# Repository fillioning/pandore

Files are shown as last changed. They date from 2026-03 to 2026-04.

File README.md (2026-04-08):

# Pandore

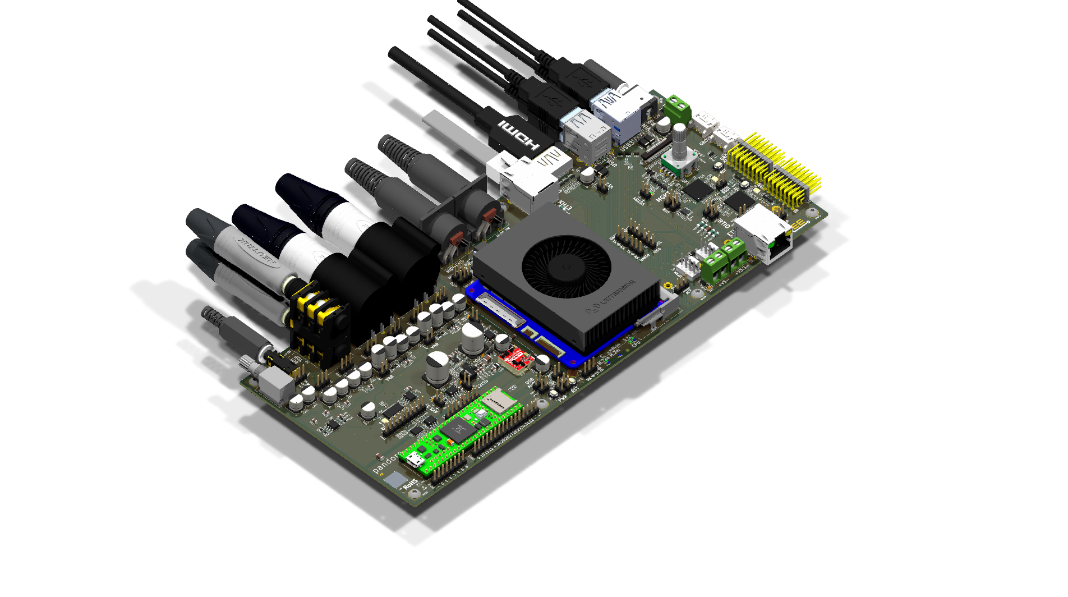
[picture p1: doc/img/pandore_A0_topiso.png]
Pandore A0


**Open-source digital audio instrument prototyping platform.**

Pandore is a custom-designed PCB built around the [LattePanda Mu](https://www.lattepanda.com/lattepanda-mu) compute module, a [Teensy 4.1](https://www.pjrc.com/store/teensy41.html) audio bridge, dual [RP2350](https://www.raspberrypi.com/products/rp2350/) microcontrollers, and a professional audio I/O chain. It provides a complete hardware foundation for building digital audio instruments, effects processors, and experimental sound tools.

## Status

**Revision A0** — PCBs fabricated (3 units). Manufacturing files released 2026-03-19. DRC passing, all components sourced.

> **PCBWay substitution:** RP2350A was unavailable at assembly time; PCBWay substituted **RP2350B (QFN-80)** for both MCU positions. RP2350A and RP2350B are binary-compatible — same cores, same peripherals, same memory map — they differ only in package size and number of exposed GPIO pins (30 vs 48). Firmware developed on RP2350A Pico boards transfers without modification.

## Board Specifications

| Parameter | Value |
|---|---|
| **Dimensions** | 260 mm x 110 mm |
| **Layers** | 4 (F.Cu / In1 / In2 / B.Cu) |
| **Components** | 804 (141 unique part numbers) |
| **Vias** | 2,217 |
| **Design tool** | KiCad 10 |

## Architecture

```
                         +-----------------+
                         |  LattePanda Mu  |
                         |  (x86-64 SBC)   |
                         +--------+--------+
                                  |
          +----------+-----------+-----------+----------+
          |          |                       |          |
 +--------+-------+  |             +---------+--------+ |
 |  RTIO MCU      |  |             |  Management MCU  | |
 |  (RP2350)      |  |             |  (RP2350)        | |
 +--------+-------+  |             +---------+--------+ |
          |          |                       |          |
 +--------+-------+  |             +---------+--------+ |
 | UART, SPI, I2C |  |             | GPIO, Power Seq, | |
 | ADC, 8x PWM    |  |             | Fan, Display     | |
 +----------------+  |             +------------------+ |
                     |                                  |
            +--------+--------+                         |
            |   Teensy 4.1    |                         |
            | (I2S-to-USB     |                         |
            |  Audio Bridge)  |                         |
            +--------+--------+                         |
                     |                                  |
            +--------+--------+               +---------+--------+
            |   CS4272 Codec  |               |   Boot, BIOS,    |
            |   (24-bit I2S)  |               |   Ethernet, M.2  |
            +-----------------+               +------------------+
```

### Compute

- **LattePanda Mu** — x86-64 SBC (Intel N100 or N305), main application processor. Recommended: DFR1147 (N100, 16 GB LPDDR5) — the N305 gives only ~13% single-core gain at ~2× cost, with no meaningful benefit for real-time audio workloads where single-thread performance dominates.
- **RTIO MCU (RP2350)** — Real-time I/O: UART, SPI, I2C, USB, ADC, 8x PWM channels
- **Management MCU (RP2350)** — System control: power sequencing, GPIO, fan, display, boot

### Audio

- **Audio/MIDI bridge:** [Teensy 4.1](https://www.pjrc.com/store/teensy41.html) — I2S-to-USB audio bridge between the CS4272 codec and the LattePanda Mu, also handles MIDI data transfer to the host computer
- **Codec:** Cirrus Logic CS4272 — stereo 24-bit ADC/DAC, I2S interface
- **Preamp:** THS4521 fully-differential amplifier + OPA1656 op-amp signal conditioning
- **Phantom power:** 48V supply via TI LM5158 flyback controller + TPS7A4001 ultra-low-noise 40V LDO post-regulation (~10 mA) for condenser microphones
- **I2S isolation:** TI ISO7762FDBQR — 6-channel digital isolator (4 forward / 2 reverse), 100 Mbps, 5000 VRMS galvanic isolation between digital and audio domains
- **I2C isolation:** TI ISO1640BDR — isolated I2C for codec control path, 2500 VRMS isolation
- **Isolated power:** Murata NXE2S1212MC — 1W isolated 12V→12V DC/DC converter for the isolated audio domain
- **MIDI isolation:** Isocom H11L1SMT optoisolator with Schmitt-trigger output on MIDI IN
- **Monitor output:** Dedicated headphone/speaker amplifier with hardware volume knob (Bourns PTR902-2020K-A103 — 10 kΩ audio taper, 20 mm shaft)
- **Input buffering:** Balanced input stage with line/mic switching
- **Output buffering:** Line-level outputs

### Power

| Rail | Voltage | Current | Purpose |
|---|---|---|---|
| 12V | Main input | LattePanda Mu, OLED drive |
| 5V | 2A (10W) | Digital logic, USB peripherals |
| 3.3V | 3A (10W) | MCUs, codec digital, I/O |
| 48V | 10 mA | Condenser microphone phantom power |
| AV5 / AV3P3 | — | Analog audio supply (isolated domain) |
| VSTBY | ~3.3V | Standby (CR2032 backup) |

**Power ICs:**

| Part | Role |
|---|---|
| Diodes AP63356Q (×2) | Synchronous buck converters (3.5A), main DC-DC regulation |
| STM LDL212DR (×3) | Ultra-low-dropout LDOs, local clean rails |
| ETEK ET20162 (×5) | Per-rail 5V load switching, 1A each |
| TI LM5158RTER | Flyback controller for 48V phantom supply |
| TI TPS7A4001DGNR | Ultra-low-noise 40V LDO, phantom post-regulation |
| Murata NXE2S1212MC | 1W isolated 12V DC/DC for audio analog domain |

- Reverse-polarity, overcurrent, and overvoltage protection
- PTC fuses (Bel Fuse) on USB VBUS
- Managed power-on sequencing via Management MCU

### Connectivity

- **Ethernet** — 2× Gigabit Ethernet via Realtek RTL8111H-CG PCIe controllers (U7, U8), 2× shielded RJ45 with isolation transformers (Würth 749020111A)
- **USB** — 8× USB from LattePanda Mu (3× USB 3.0 + 5× USB 2.0); 2× USB-C receptacles for Teensy 4.1 bridge
- **MIDI** — 5-pin DIN IN/OUT with H11L1 optoisolation
- **Display** — 24-pin 0.5mm FPC ZIF connector (GCT FFC2A32-24-T) for OLED status display (SSD1309, 128×64 px, 1.54") — see [Components Requiring Separate Assembly](#components-requiring-separate-assembly)
- **M.2 Key-M** — PCIe x4 (NVMe SSD)
- **M.2 Key-A+E** — WiFi/Bluetooth (tested: Intel AX210 — WiFi 6E tri-band + BT 5.3) or alternate storage
- **Expansion headers** — GPIO, analog, I/O breakouts; 2× Grove I2C connectors; I2S header; UART debug

### User Interface

- **Encoder:** Bourns PEL12T-4225T-S1024 — 24 PPR optical rotary encoder with momentary push switch and RGB LED illumination
- **Tactile switches:** 4× C&K PTS810 momentary switches (B1–B4)
- **Volume knob:** Bourns PTR902-2015K-B103 potentiometer (monitor output level)
- **RGBA LED:** AMS-OSRAM multi-colour LEDs — blue (×3), green (×4), orange (×7), red (×1) status/indicator outputs

### Sensors

- **BMI270** — 6-axis IMU (accelerometer + gyroscope) for motion-based control

### Flash Storage

3× Winbond W25Q128JVSIM (128 Mbit / 16 MB, QSPI):
- U2 — BIOS flash (LattePanda Mu)
- U5 — RTIO MCU flash (RP2350, U3)
- U6 — Management MCU flash (RP2350, U4)

### Thermal

- PWM-controlled fan driver circuit
- Three heatsink options: active cooler, thin passive, fanless

## Audio Performance

See **[Audio Performance](AUDIO_PERFORMANCE.md)** for the full signal chain, component specs, system-level estimates, physical I/O, and performance class.

**Highlights:** 24-bit / 192 kHz, 114 dB dynamic range, -100 dB THD+N, 5000 VRMS galvanic isolation, 2× Neutrik combo XLR+TRS inputs with 48V phantom power.

## Repository Structure

```
pandore/
  hw/               Schematics (.kicad_sch) and PCB layout (.kicad_pcb)
  doc/
    arch/           Architecture diagrams (draw.io)
    img/            Board renders
    reference/      Datasheets, app notes, design guides (PDF)
  lib/              3D models (.step), KiCad symbols and footprints
  release/          Manufacturing artifacts (Gerbers, BOM, placement, 3D)
```

### Schematic Hierarchy

The top-level schematic (`pandore.kicad_sch`) references 24 sub-sheets organized by subsystem:

**Audio** — `audio`, `audio-codec`, `audio-inputs`, `audio-inbuf`, `audio-outputs`, `audio-outbuf`, `audio-isolation`, `audio-monitor`, `audio-power`

**Compute** — `computer`, `cpumod`, `mcu`, `mgmtmcu`, `rtmcu`

**Power** — `power`, `audio-power`

**Interface** — `eth`, `usbport`, `midi`, `display`, `extraport`, `mdot2`

**System** — `bootctl`, `bios`, `fan`

## Components Requiring Separate Assembly

The PCBWay PCBA order covers all SMD components. The following through-hole and DNP parts must be sourced and hand-soldered separately. BOM part numbers are listed; substitutions are noted where a different part is recommended over the original BOM.

| BOM# | Per board | Ref | Description | Part (installed) | Notes |
|---|---|-----|---|---|---|
| 40 | 1 | E1 | Encoder + RGB LED + switch | Bourns **PEL12T-4225T-S1024** | 24 PPR, push switch, RGB illuminated |
| 47 | 2 | J4, J5 | Mic/Line input combo jack | Neutrik **NCJ9FI-H-0** | XLR + 6.35mm TRS + 3-way switch |
| 50 | 2 | J8, J9 | Ethernet RJ45 | Amphenol **RJE58-188-5411** | 8P8C shielded, dual LEDs, Cat5e |
| 51 | 2 | J10, J11 | MIDI DIN | Same Sky **SDS-50J** | 5-pin DIN 180° |
| 52 | 1 | J12 | Line output TRS | Neutrik **NSJ12HF-1** | 6.35mm stacking stereo |
| 55 | 2 | J15, J16 | GPIO expansion header | Samtec **MTSW-108-22-L-T-330-RA** | 3×8 right-angle, 2.54mm pitch |
| 56 | 2 | J17, J18 | Grove connectors | TE **440055-4** | HPI 2.0mm R/A THT (replaces BOM 2041145-4, same family) |
| 105 | 1 | R273 | Headphone volume pot | Bourns **PTR902-2020K-A103** | Audio taper, 20mm shaft (replaces BOM 2015K-B103, linear, 15mm) |
| — | 1 | J25 | OLED display panel | **Microtips REX012864AYAP3N00000** (primary) or Midas MCOT128064B1V-WM (alt) | SSD1309, 128×64, 24-pin 0.5mm FPC; J25 ZIF socket is PCBWay-assembled |
| — | 1 | J28/J29 | Audio/MIDI bridge module | **PJRC Teensy 4.1** | J28/J29 USB-C receptacles are PCBWay-assembled |
| — | 1 | J13 | NVMe SSD | User choice | M.2 2280 Key-M, PCIe x4 |
| — | 1 | J19 | WiFi/BT module | **Intel AX210** (WiFi 6E + BT 5.3) | M.2 2230 Key-E |

---

## Manufacturing

The `release/` directory contains two packages dated 2026-03-19 (revision A0):

- **`pandore_*_A0_pcba.zip`** — PCBA package: Gerbers, drill files, BOM (.csv), pick-and-place (.pos)
- **`pandore_*_A0_release.zip`** — Full release: PCBA files + 3D assembly model (.step), assembly drawings (PDF), rendered board images, ERC/DRC reports

4-layer stackup. 2,439 drill holes. All components have manufacturer part numbers assigned.

## Reference Documentation

The `doc/reference/` directory includes datasheets and design guides used during development:

- RP2350 datasheet and hardware design guide
- LattePanda Mu evaluation kit guide and carrier board reference
- CS4272 codec (via SuperAudioBoard design guide and schematic)
- THAT1512 microphone preamp gain configuration (reference design)
- 48V phantom power supply design (TI SBOA320A + ultra-low-noise RAQ approach)
- Analog circuit design references (Analog Secrets series, AES mic preamp paper)
- THAT Corporation mic preamp reference design (git submodule)

## Requirements

- [KiCad 10](https://www.kicad.org/) to open and edit schematics and PCB layout
- [draw.io](https://app.diagrams.net/) to view architecture diagrams

## Credits

Designed by **Vincent Fillion** at [Artificiel](https://artificiel.org), with the help of **Alexandre Burton**.

Hardware engineering and KiCad source files by **Laurence Deschênes Villeneuve** ([@laurencedv](https://github.com/laurencedv)).

## License

This project is licensed under the [CERN Open Hardware Licence Version 2 — Strongly Reciprocal (CERN-OHL-S-2.0)](https://ohwr.org/cern_ohl_s_v2.txt).

You are free to use, study, modify, and distribute this design, provided that:
- You credit the original authors
- You distribute any modified versions under the same licence
- You make the source files available

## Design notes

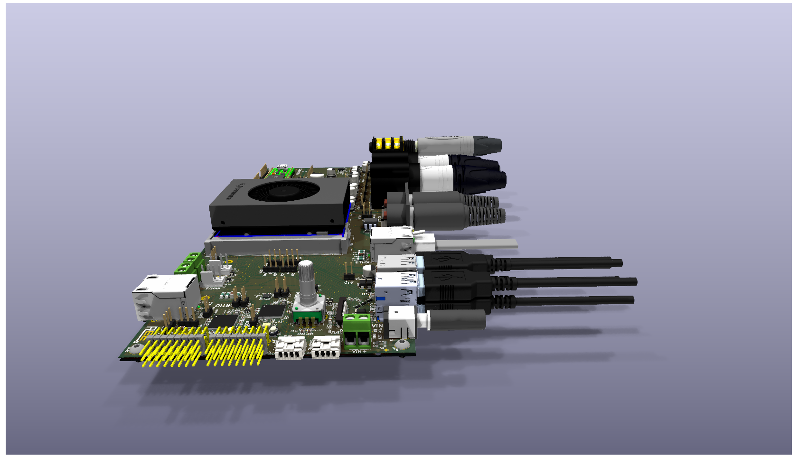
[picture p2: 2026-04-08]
doc/img/pandore-a0-connright.png

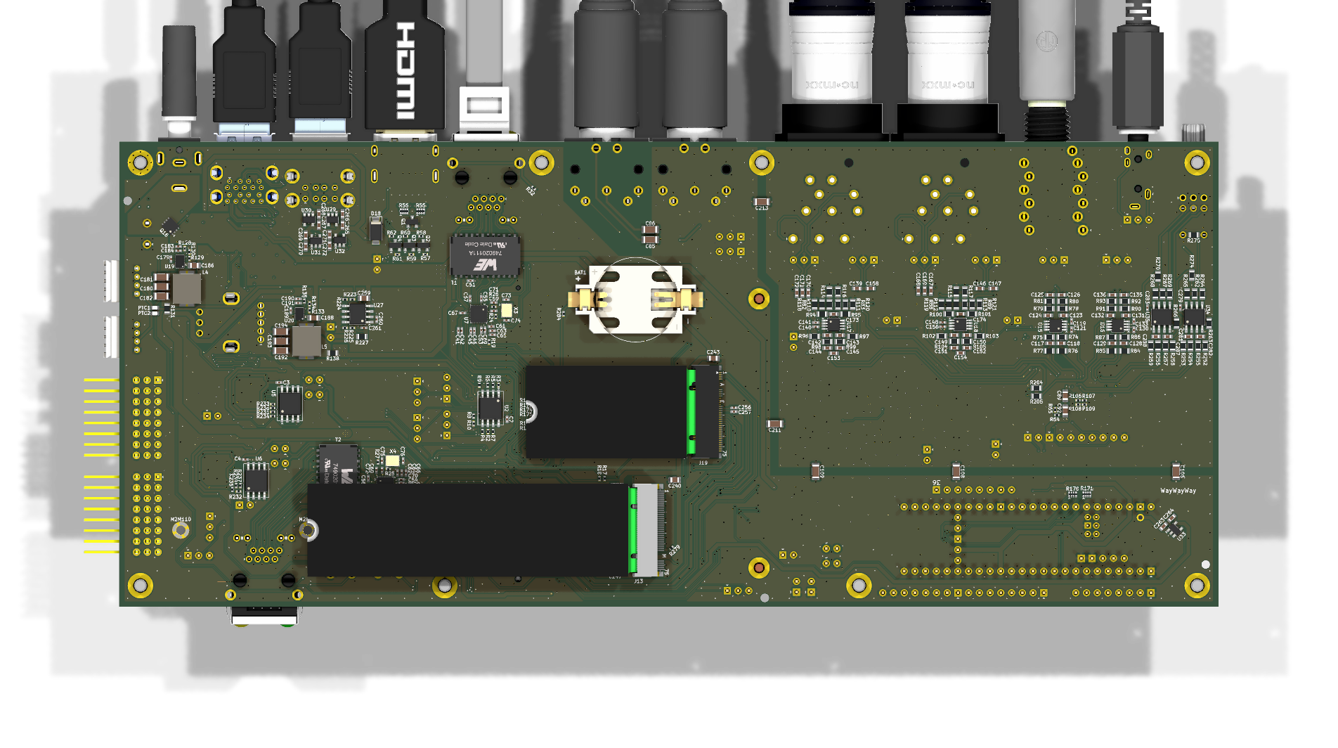
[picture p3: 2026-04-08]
doc/img/pandore_A0_bot.png

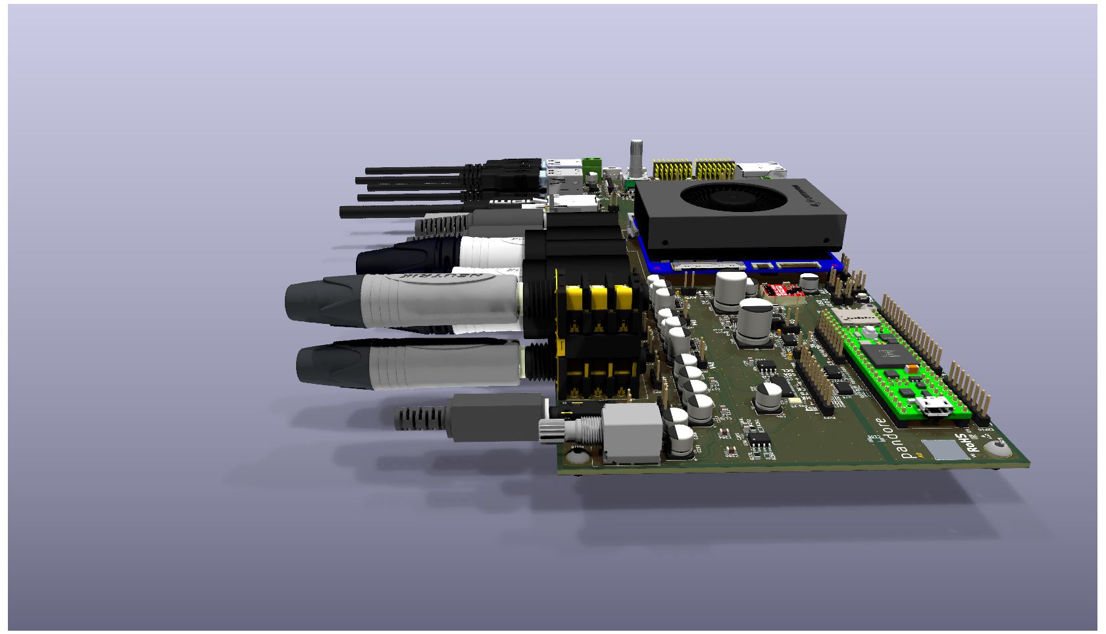
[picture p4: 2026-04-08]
doc/img/pandore-a0-connleft.png

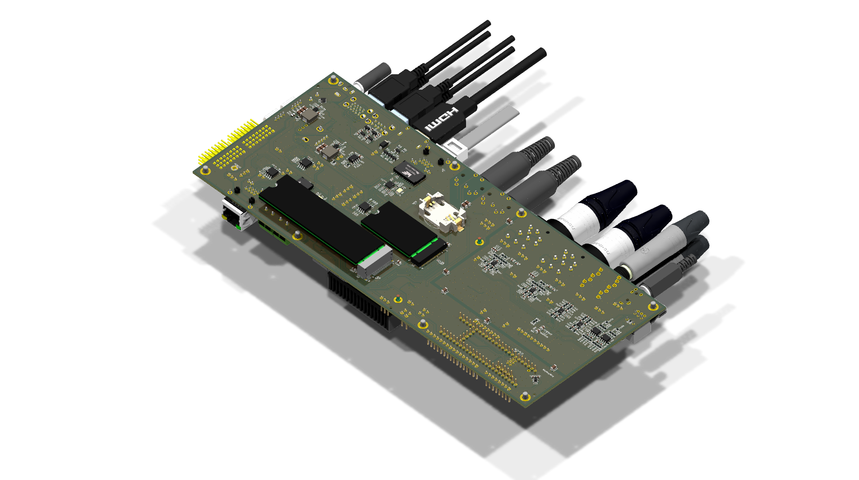
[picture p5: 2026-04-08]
doc/img/pandore_A0_botiso.png

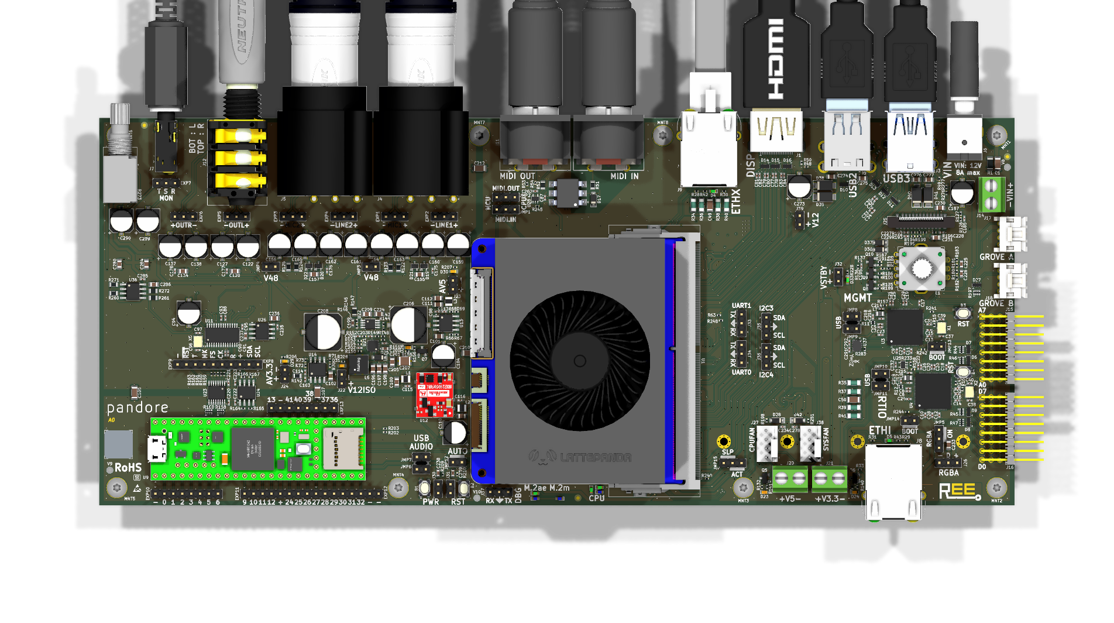
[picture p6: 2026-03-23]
doc/img/pandore_A0_top.png

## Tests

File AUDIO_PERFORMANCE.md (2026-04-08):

# Audio Performance

## Signal Chain

```
Mic/Line In (Neutrik XLR+TRS combo)
    → THS4521 Diff Amp → OPA1656 Conditioning → Input Buffer
        → CS4272 ADC (24-bit, up to 192 kHz)
            → I2S → ISO7762 Galvanic Isolation → I2S
                → Teensy 4.1 (I2S ↔ USB Audio Bridge)
                    → USB → LattePanda Mu
                        → USB → Teensy 4.1
                            → I2S → ISO7762 → I2S
                                → CS4272 DAC
                                    → Output Buffer → Line Out (Neutrik TRS)
                                    → Monitor Amp (volume knob) → Headphones (3.5mm TRS)
```

## Component Specs

| Component | Role | Key Specs |
|---|---|---|
| **CS4272** (Cirrus Logic) | Stereo codec | 24-bit, 4–192 kHz, 114 dB dynamic range (A-wtd), -100 dB THD+N |
| **THS4521** (TI, ×4) | Fully-differential amp | 4.6 nV/√Hz noise, -112 dB THD+N @ 1 kHz, 145 MHz BW, 490 V/µs, 102 dB CMRR |
| **OPA1656** (TI, ×4) | Dual op-amp | 2.9 nV/√Hz noise, -131 dB THD @ 1 kHz, 53 MHz GBW, 24 V/µs |
| **ISO7762** (TI) | I2S digital isolator | 6-ch (4F/2R), 100 Mbps, 11 ns delay, 5000 VRMS isolation |
| **ISO1640** (TI) | Isolated I2C (codec control) | 1 Mbps, 2500 VRMS isolation |
| **NXE2S1212MC** (Murata) | Isolated 12V DC/DC | 1W, 12V→12V, powers isolated audio domain |
| **H11L1** (Isocom) | MIDI IN optoisolator | Schmitt-trigger output |
| **Teensy 4.1** (PJRC) | Audio/MIDI bridge | Cortex-M7 @ 600 MHz, 2× I2S, USB Audio class-compliant |

## System-Level Estimates

The analog front-end (OPA1656 at -131 dB THD, THS4521 at -112 dB) significantly exceeds the codec's performance floor — the **CS4272 is the limiting factor**, not the preamp stage.

| Parameter | Expected Value |
|---|---|
| **Dynamic range** | 112–114 dB (A-weighted) |
| **THD+N (system)** | -98 to -100 dB (codec-limited) |
| **Noise floor** | ~-114 dBFS (A-weighted) |
| **Max sample rate** | 192 kHz / 24-bit |
| **USB audio latency** | ~5–10 ms round-trip (buffer-dependent) |
| **Frequency response** | 20 Hz – 90 kHz (at 192 kHz) |
| **Phantom power** | 48V / 10 mA |
| **Channel separation** | >100 dB |
| **Galvanic isolation** | 5000 VRMS (digital ↔ audio domain) |

## Physical I/O

| Connector | Part | Type |
|---|---|---|
| Mic/Line In (×2) | Neutrik NCJ9FI-H-0 | Combo XLR + 6.35mm TRS + 3-way switch |
| Line Out (×1) | Neutrik NSJ12HF-1 | 6.35mm TRS |
| Monitor | Same Sky SJ3-35083B-TR | 3.5mm TRS |
| MIDI In/Out | Same Sky SDS-50J (×2) | 5-pin DIN |
| Teensy USB | Same Sky CPG-23-SMT-TR (×2) | USB-C |

## Performance Class

Comparable to prosumer interfaces (Focusrite Scarlett, MOTU M4). The 114 dB dynamic range is well above the noise floor of any live performance or instrument prototyping scenario. The analog front-end is essentially transparent — the OPA1656's -131 dB THD provides substantial headroom over the codec.

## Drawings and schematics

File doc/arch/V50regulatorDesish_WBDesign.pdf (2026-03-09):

## WEBENCH ® Design Report

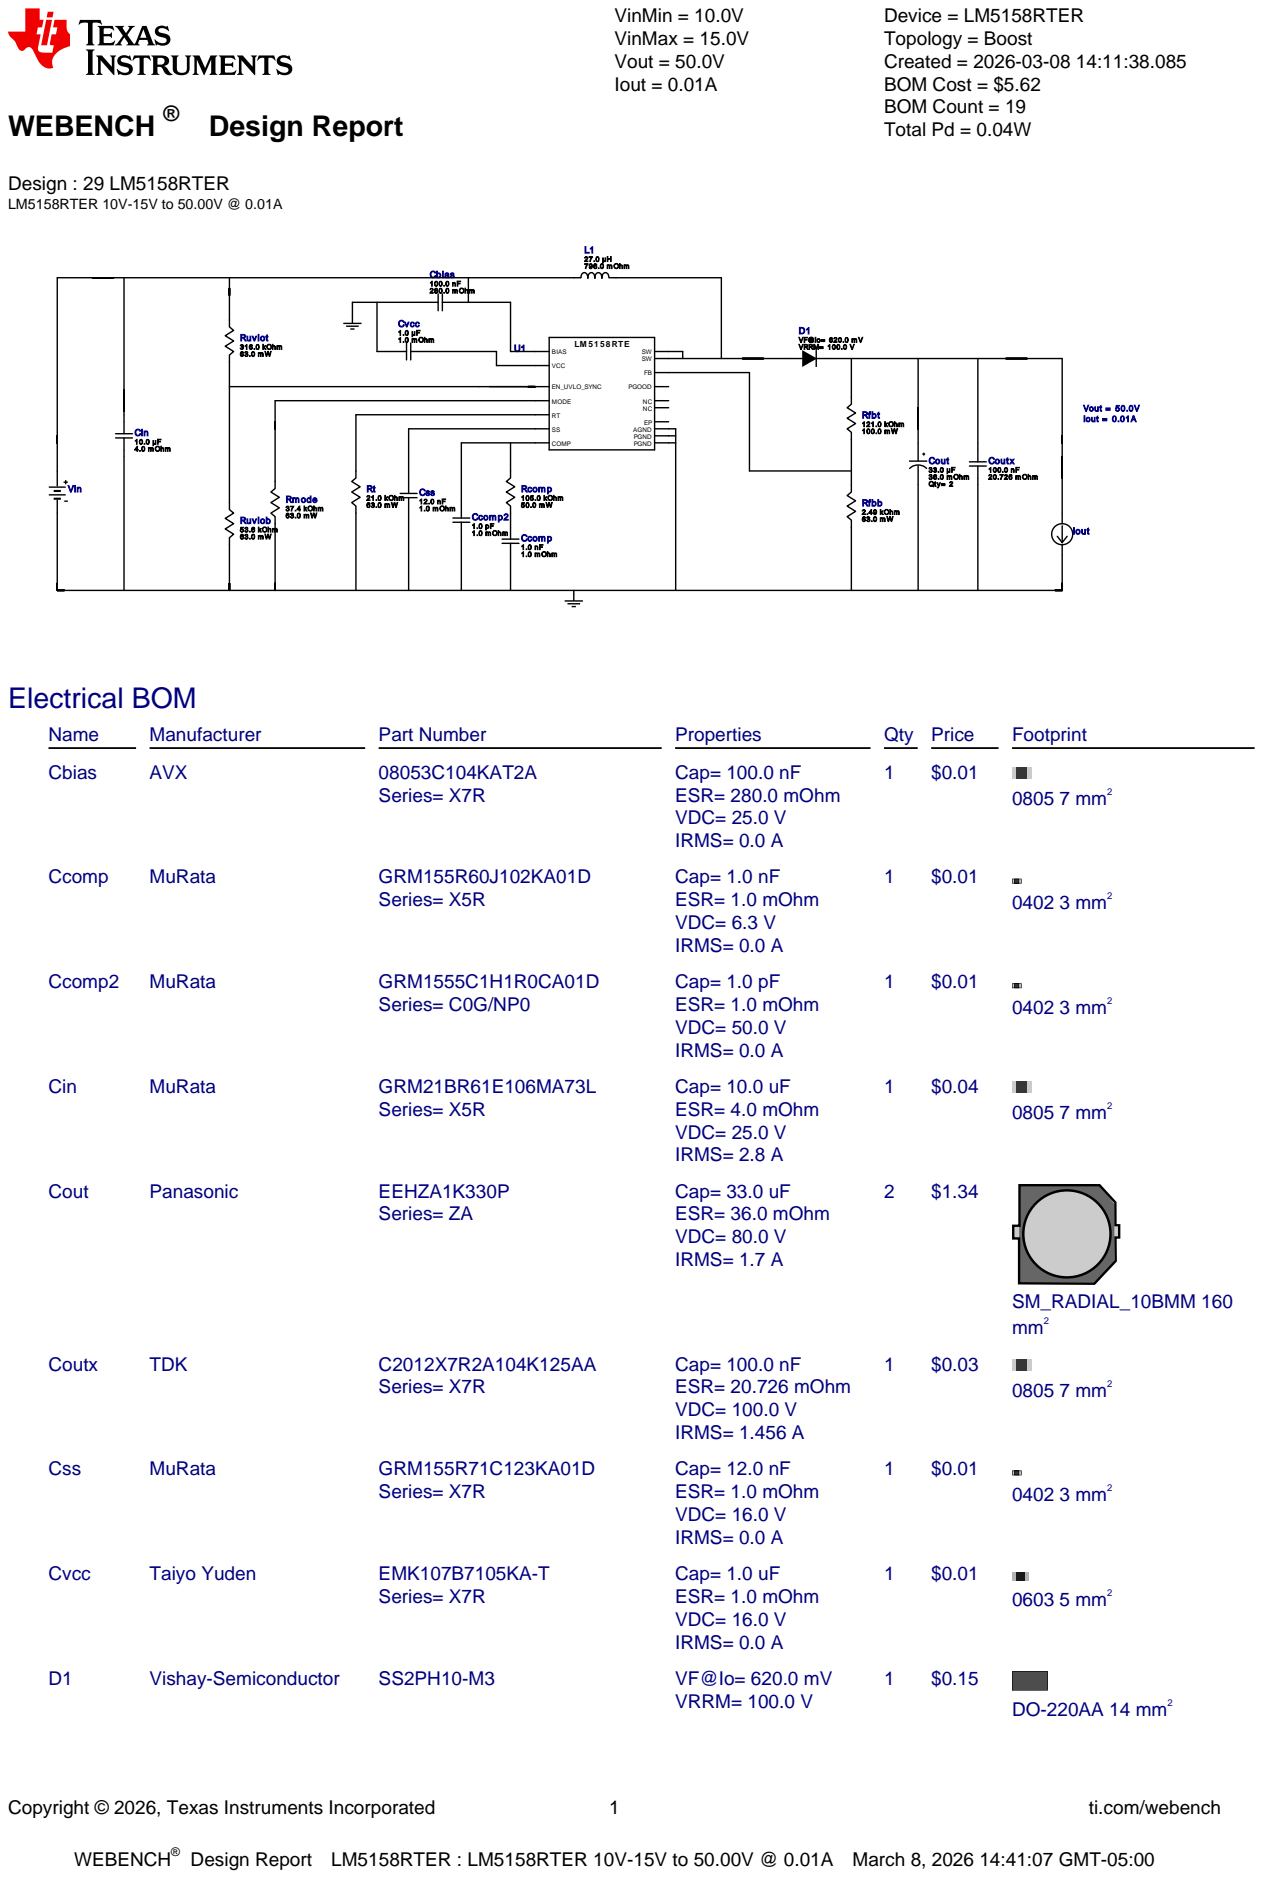
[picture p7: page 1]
Copyright © 2026, Texas Instruments Incorporated; ti.com/webench; WEBENCH®; Design : 29 LM5158RTER LM5158RTER 10V-15V to 50.00V @ 0.01A; VinMin = 10.0V VinMax = 15.0V Vout = 50.0V Iout = 0.01A; Device = LM5158RTER Topology = Boost Created = 2026-03-08 14:11:38.085 BOM Cost = $5.62 BOM Count = 19 Total Pd = 0.04W; Rt 21.0 kOhm; Ccom p 1.0 nF 1.0 m Ohm; Cin 10.0 µF 4.0 m Ohm; Rfbb 2.49 kOhm 63.0 m W; Rfbt 121.0 kOhm; L1 27.0 µH 796.0 m Ohm; Ruvlob 53.6 kOhm 63.0 m W; Ruvlot 316.0 kOhm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

VRRM= 100.0 V LM 5 1 5 8 RTE

Design Report LM5158RTER : LM5158RTER 10V-15V to 50.00V @ 0.01A March 8, 2026 14:41:07 GMT-05:00

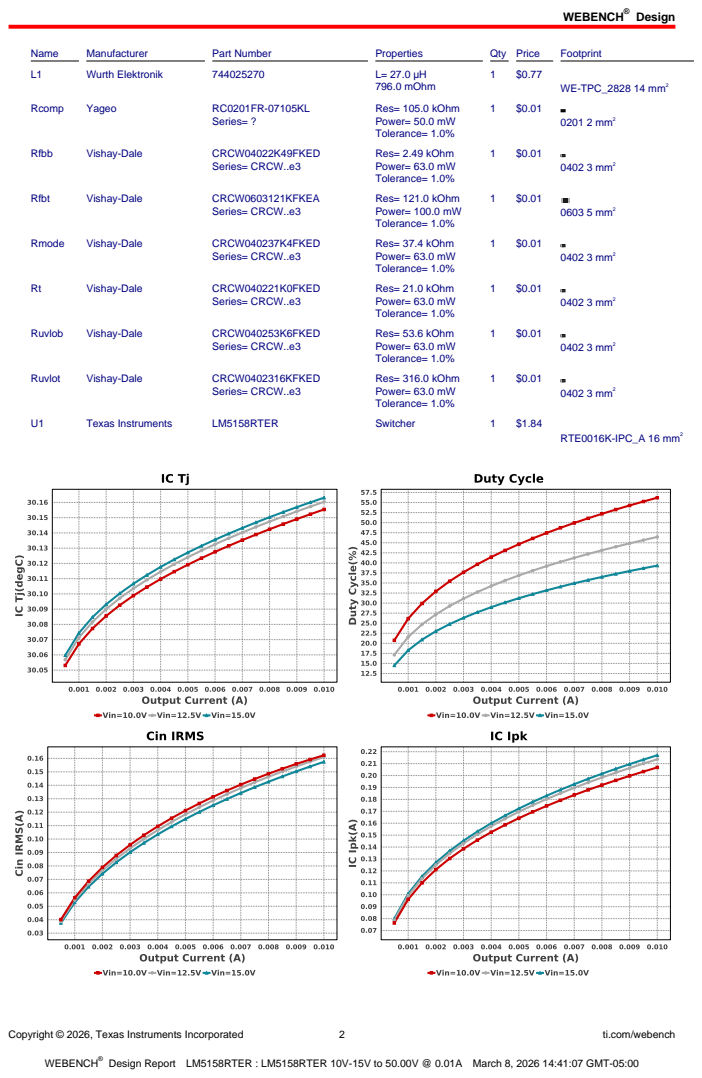
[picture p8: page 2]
Design; Copyright © 2026, Texas Instruments Incorporated; ti.com/webench; Name; Manufacturer; Part Number; Properties; Qty Price; Footprint; Wurth Elektronik; 796.0 mOhm; WE-TPC_2828 14 mm²; Rcomp; Yageo; Series= ?; Res= 105.0 kOhm Power= 50.0 mW Tolerance= 1.0%; 0201 2 mm²; Rfbb; Vishay-Dale; CRCW04022K49FKED; Series= CRCW..e3; Res= 2.49 kOhm Power= 63.0 mW Tolerance= 1.0%; 0402 3 mm²; Rfbt; CRCW0603121KFKEA; Res= 121.0 kOhm Power= 100.0 mW Tolerance= 1.0%; 0603 5 mm²; Rmode; CRCW040237K4FKED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

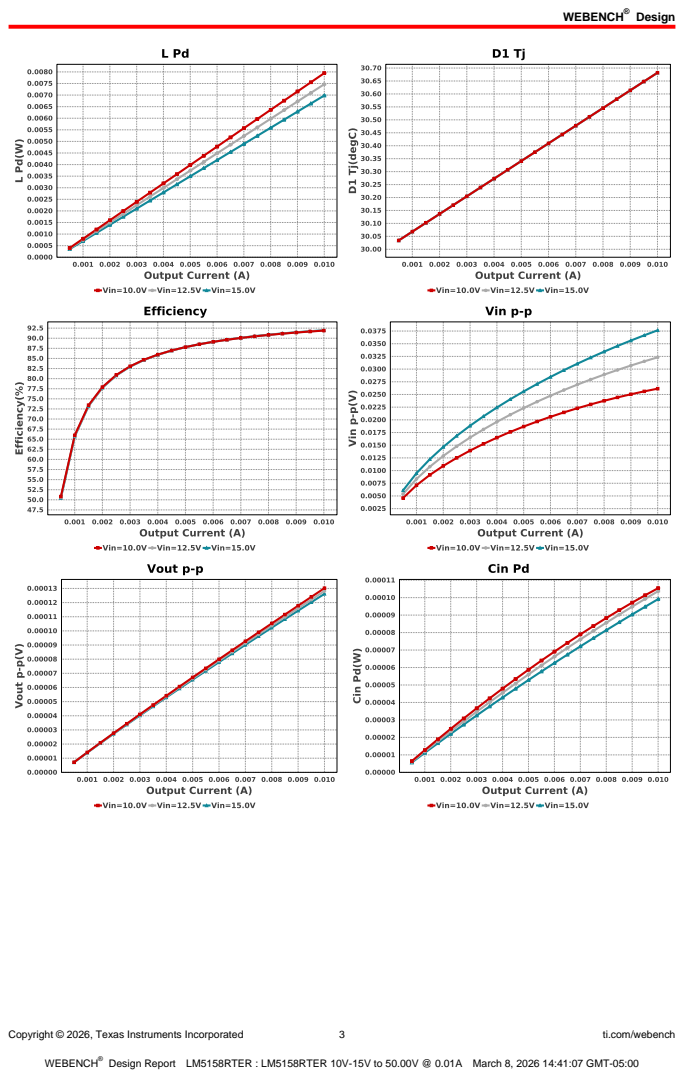
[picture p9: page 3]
Copyright © 2026, Texas Instruments Incorporated; ti.com/webench

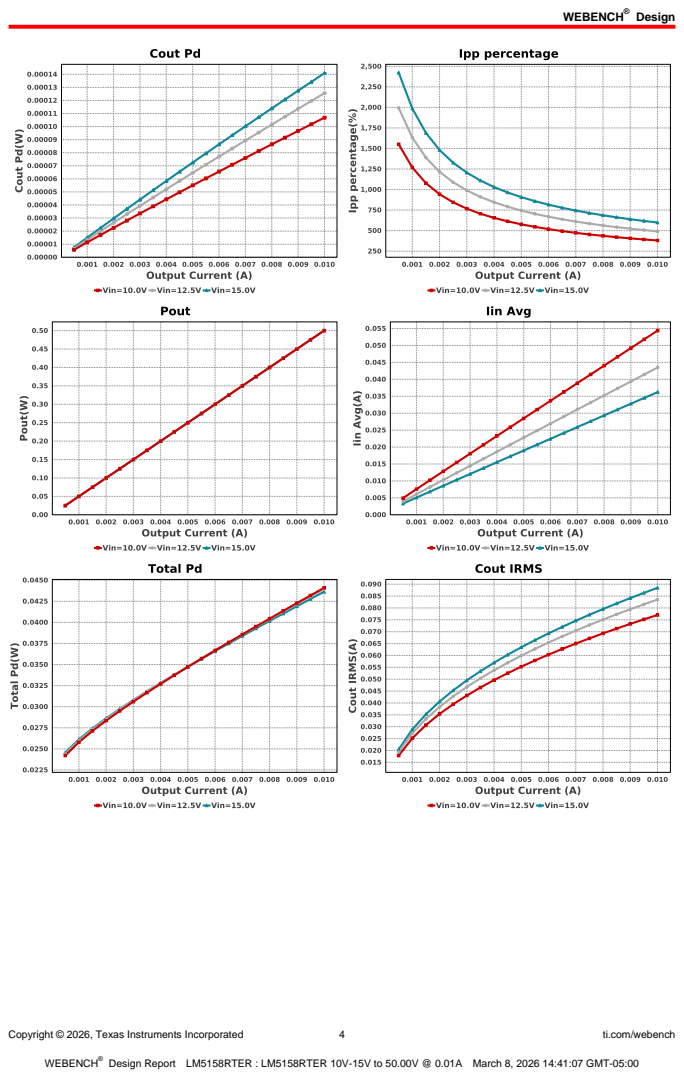
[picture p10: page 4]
Copyright © 2026, Texas Instruments Incorporated; ti.com/webench

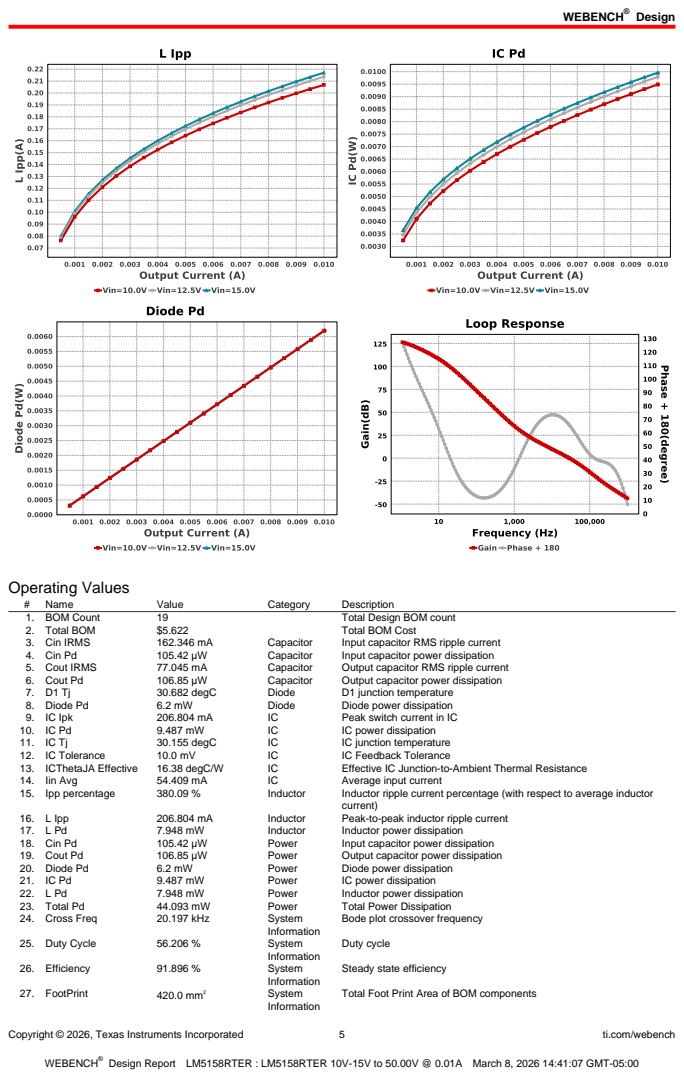
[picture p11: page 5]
Copyright © 2026, Texas Instruments Incorporated; ti.com/webench; Operating Values; Name; Value; Category; Description; 1. BOM Count; Total Design BOM count; 2. Total BOM; Total BOM Cost; 3. Cin IRMS; Capacitor; Input capacitor RMS ripple current; 4. Cin Pd; Input capacitor power dissipation; 5. Cout IRMS; Output capacitor RMS ripple current; 6. Cout Pd; Output capacitor power dissipation; 30.682 degC; Diode; D1 junction temperature; 8. Diode Pd; Diode power dissipation; 9. IC Ipk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

Bode plot crossover frequency

Steady state efficiency

Total Foot Print Area of BOM components

Copyright © 2026, Texas Instruments Incorporated | 6 | ti.com/webench
# | Name | Value | Category | Description

28. Frequency | 1.007 MHz | System
| | | Information | Switching frequency
29. Gain Marg | -42.993 dB | System
| | | Information | Bode Plot Gain Margin
30. Iout | 10.0 mA | System
| | | Information | Iout operating point
31. Low Freq Gain | 122.835 dB | System
| | | Information | Gain at 1Hz
32. Mode | DCM | System
| | | Information | Conduction Mode
33. Phase Marg | 70.569 deg | System
| | | Information | Bode Plot Phase Margin
34. Pout | 500.0 mW | System
| | | Information | Total output power
35. Vin | 10.0 V | System
| | | Information | Vin operating point
36. Vin p-p | 26.145 mV | System
| | | Information | Input Source ripple voltage
37. Vout | 50.0 V | System
| | | Information | Operational Output Voltage
38. Vout Actual | 49.594 V | System
| | | Information | Vout Actual calculated based on selected voltage divider resistors
39. Vout Tolerance | 2.999 % | System
| | | Information | Vout Tolerance based on IC Tolerance (no load) and voltage divider resistors if applicable
40. Vout p-p | 130.206 µV | System
| | | Information | Peak-to-peak output ripple voltage

## Design Inputs

Name | Value | Description
Iout | 10.0 m | Maximum Output Current
SoftStart | 1.0 ms | Soft Start Time (ms)
VinMax | 15.0 | Maximum input voltage
VinMin | 10.0 | Minimum input voltage
Vout | 50.0 | Output Voltage
| base_pn | | LM5158 | Base Product Number
source | DC | Input Source Type
Ta | 30.0 | Ambient temperature
| UserFsw | | 1000.0 k | Customer Selected Frequency


Copyright © 2026, Texas Instruments Incorporated | 7 | ti.com/webench

## Assembly

## Component Testing

Some published data on components in datasheets such as Capacitor ESR and Inductor DC resistance is based on conservative values that will guarantee that the components always exceed the specification. For design purposes it is usually better to work with typical values. Since this data is not always available it is a good practice to measure the Capacitance and ESR values of Cin and Cout, and the inductance and DC resistance of L1 before assembly of the board. Any large discrepancies in values should be electrically simulated in WEBENCH to check for instabilities and thermally simulated in WebTHERM to make sure critical temperatures are not exceeded.
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

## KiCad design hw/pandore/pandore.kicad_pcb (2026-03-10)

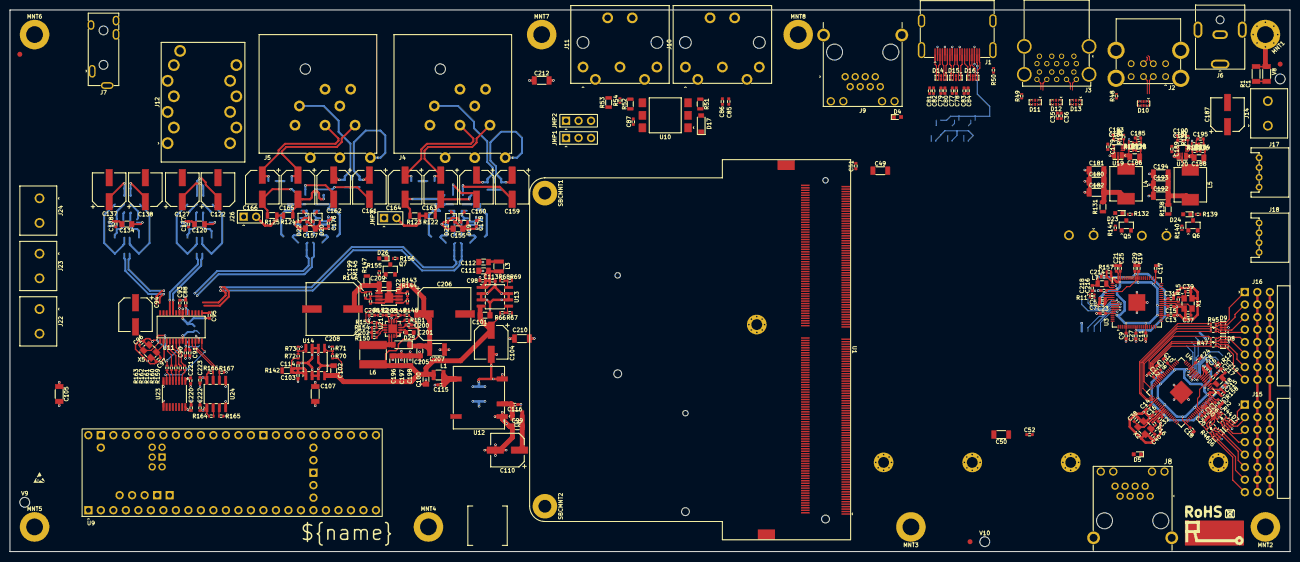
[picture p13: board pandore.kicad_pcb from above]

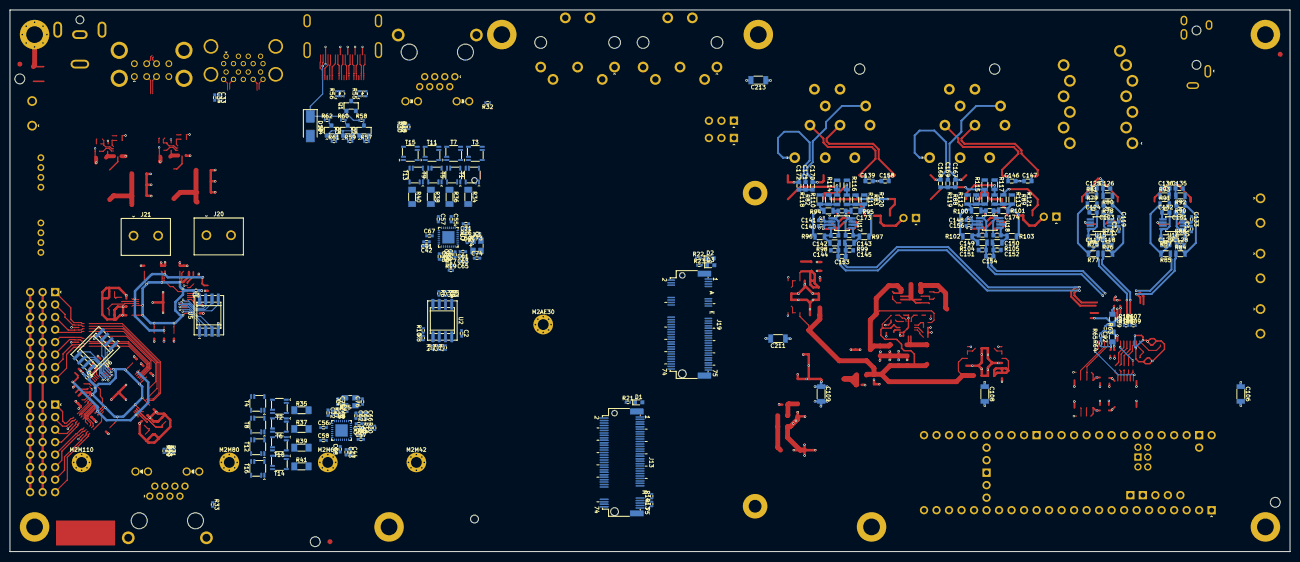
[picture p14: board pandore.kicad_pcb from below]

Board: 4 copper layers, 260.0 x 110.0 mm, 530 parts (227 on the bottom side), 432 nets.

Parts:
C1: 10nF, 630V, X7R; CAPC3216
C2, C3, C4, C5, C6, C7, C8, C9, C10, C11, C12, C13, C14, C15, C16, C17, C18, C19, C20, C21, C22, C23, C24, C25, C26, C27, C28, C29, C30, C33, C34, C35, C36, C41, C42, C43, C44, C45, C46, C47, C48, C51, C52, C53, C54, C55, C56, C57, C58, C59, C60, C61, C62, C67, C68, C69, C70, C71, C72, C77, C78, C79, C80, C81, C82, C83, C84, C85, C86, C87, C88, C90, C91, C93, C95, C113, C114, C119, C133, C140, C156, C175, C176, C177, C178, C179, C189, C220, C221, C222, C223: 100nF, 16V, X7R; CAPC1005
C31, C32, C63, C64, C65, C66, C98, C103, C214, C215, C216, C217, C218, C219: 4.7µF, 6.3V, X5R; CAPC1005
C37, C38, C39, C40: 15pF, 6.3V, X7R; CAPC1005
C49, C50: 1nF, 1000V, X7R; CAPC3216
C73, C74, C75, C76, C96, C97: 12pF, 6.3V, X7R; CAPC1005
C89, C92: 10µF, 16V, X5R; CAPC2012
C94, C104, C110: 47µF, 25V, 20%; CAPAE630Xxxx
C99, C100, C101, C102, C111, C112, C120, C134, C155, C157, C186, C188, C196, C197, C198: 10µF, 25V, X5R; CAPC2012
C105, C106, C107, C108, C109, C210, C211, C212, C213: 100pF, 1kV, X5R; CAPC3216
C115, C116, C200: 100nF, 25V, X7R; CAPC1005
C117, C118, C128, C129: 1.3nF, 16V, C0G; CAPC1608
C121, C130, C141, C148: 220nF, 16V, X7R; CAPC1005
C122, C127, C137, C138, C159, C160, C161, C162, C187: 100µF, 25V, 20%; CAPAE630Xxxx
C123, C124, C131, C132: 300pF, 16V, C0G; CAPC1608
C125, C126, C135, C136: 33nF, 16V, C0G; CAPC1608
C139, C144, C145, C146, C147, C151, C152, C158, C167, C168, C169, C170, C171, C172, C173, C174: 100pF, 50V, C0G; CAPC1608
C142, C143, C149, C150: 1nF, 16V, C0G; CAPC1608
C153, C154: 2.7nF, 16V, C0G; CAPC1608
C163, C164, C165, C166: 47µF, 100V, 20%; CAPAE630Xxxx
C180, C181, C182, C192, C193, C194: 22µF, 25V, X5R; CAPC3216
C183, C190, C204: 1nF, 16V, X7R; CAPC1005
C184, C191: 68pF, 10V, X7R; CAPC1005
C185, C195: 47pF, 10V, X7R; CAPC1005
C199: 10nF, 100V, X7R; CAPC1005
C201: 1µF, 16V, X7R; CAPC1608
C202: 12nF, 16V, X7R; CAPC1005
C203: 1pF, 16V, X7R; CAPC1005
C205, C209: 100nF, 100V, X7R; CAPC2012
C206, C208: 56µF, 100V, 20%; CAPAE1000Xxxx
C207: 10µF, 100V, X5R; CAPC3225
D1, D2, D3, D4, D5, D23, D24, D26: green; LEDM1608X80
D6, D7, D8, D9, D10, D11, D12, D13, D14, D15, D16: 5V; DFN50P100X250X55-10_ESD204
D17: 75V, 150mA, 1V@100mA; sod-123
D18: 40V, 3A, 500mV@3A; dio_sma
D19, D20, D21, D22: 75V, 140mA, 1.25V@150mA; SOT65P210X90-3
D25: 100V, 150mA, 450mV@10mA; sod-123
J1: HDMI; te_1747981-1
J2: USB2-A_2stacked; USB2_A_RCPT_HORZ_2STACKED
J3: USB3-A_2stacked; USB3_A_RCPT_HORZ_2STACKED
J4, J5: XLR+TRS6.35+3SW; neutrik_ncj9fi-h-0
J6: VIN; samesky_PJ-063BH
J7: TRS; samesky_SJ3-3508x
J8, J9: 8p8c_2led_shield; amphenol_RJE58-188-54x1-0x
J10: MIDI_in; samesky_SDS-50J
J11: MIDI_out; samesky_SDS-50J
J12: TRS; neutrik_nsj12hf-1
J13: NGFF_M.2_M; NGFF_M.2_CONN
J14: VIN; Wurth_691137710002
J15: AIO; HDR254P3X8-THRA
J16: DIO; HDR254P3X8-THRA
J17, J18: GROVE; te_2041145-4
J19: NGFF_M.2_AE; NGFF_M.2_CONN
J20: V5; Wurth_691137710002
J21: V3.3; Wurth_691137710002
J22: V12ISO; Wurth_691137710002
J23: AV5; Wurth_691137710002
J24: AV3P3; Wurth_691137710002
J26: PPWR; HDR254P1X02-TH
JMP1: MIDIRX; HDR254P1X03-TH
JMP2: MIDITX; HDR254P1X03-TH
JMP3: PPWR; HDR254P1X02-TH
L1, L2, L3: 10µH; INDC2520
L4, L5: 8.2µH, 5A; Eaton_HPAL1V0630
L6: Ind; WE_IND5030
L7, L8: 3.3µH, 1.8A; INDC2012
M2AE30, M2M42, M2M60, M2M80, M2M110: M2; mnt_M2_ele
MNT1: MNT-CHASSIS; mnt_M3_ele
MNT2, MNT3, MNT4, MNT5, MNT6, MNT7, MNT8: Mounting; mnt_M3
Q1, Q2, Q3, Q4, Q5, Q6, Q7: MOSFET_EN-N; SOT95P280X100-3
R1: 1MΩ, 5%, 250mW; RESC3216
R2, R3, R4, R5, R6, R7: 0, 5%, 63mW; RESC1005
R8, R9, R10, R13, R17, R18, R19, R20, R64, R66, R67, R68, R69, R70, R71, R72, R73, R106, R107, R108, R109, R129, R130, R133, R134, R140, R141, R143, R144, R145, R146, R155: 10kΩ, 1%, 63mW; RESC1005
R11, R12: 27Ω, 5%, 63mW; RESCAXSR65P100X100X35-4
R14, R15, R16, R21, R22, R23, R42, R43, R65, R132, R139, R156: 1kΩ, 1%, 63mW; RESC1005
R24, R25: 1MΩ, 1%, 63mW; RESC1005
R26, R27: 2.49kΩ, 1%, 63mW; RESC1005
R28, R29, R30, R31: 470Ω, 1%, 63mW; RESC1005
R32, R33, R48, R49, R50, R54, R63: 0Ω, 5%, 63mW; RESC1005
R34, R35, R36, R37, R38, R39, R40, R41: 75Ω, 1%, 250mW; RESMELF0204
R44, R45, R46, R47, R55, R56: 560Ω, 5%, 63mW; RESCAXSR50P200X100X35-8
R51: 220Ω, 1%, 250mW; RESC2012
R52: 10Ω, 1%, 250mW; RESC2012
R53: 33Ω, 1%, 250mW; RESC2012
R57, R58, R59, R60, R61, R62, R164, R165, R166, R167: 2.2kΩ, 1%, 63mW; RESC1005
R74, R75, R76, R77, R78, R79, R84, R85, R86, R87, R90, R91: 5.1kΩ, 0.5%, thin film; RESC2012
R80, R81, R92, R93: 100Ω, 1%, thin film; RESC2012
R82, R83, R88, R89: 10Ω, 1%, thin film; RESC2012
R94, R95, R96, R97, R100, R101, R102, R103, R118, R119, R120, R121: 1kΩ, 0.5%, thin film; RESC2012
R98, R99, R104, R105: 40.2Ω, 1%, thin film; RESC2012
R110, R112: 9.09kΩ, 0.5%, thin film; RESC2012
R111, R113: 9.01kΩ, 0.5%, thin film; RESC2012
R114, R115, R116, R117: 47kΩ, 0.5%, thin film; RESC2012
R122, R123, R124, R125: 6.8kΩ, 0.5%, thin film; RESC2012
R126: 158kΩ, 1%, 63mW; RESC1005
R127, R137: 30kΩ, 1%, 63mW; RESC1005
R128: 68.1kΩ, 1%, 63mW; RESC1005
R131, R138, R142, R147: 0Ω, 5%, thin film; RESC2012
R135: 100kΩ, 1%, 63mW; RESC1005
R136: 93.1kΩ, 1%, 63mW; RESC1005
R148, R153: 316kΩ, 1%, 63mW; RESC1005
R149, R154: 53.6kΩ, 1%, 63mW; RESC1005
R150: 37.4kΩ, 1%, 63mW; RESC1005
R151: 21kΩ, 1%, 63mW; RESC1005
R152: 105kΩ, 1%, 63mW; RESC1005
R157, R158: 33Ω, 1%, 63mW; RESC1005
R159, R160, R161, R162, R163: 49.9Ω, 1%, 63mW; RESC1005
SBCMNT1: SBC-CHASSIS; spacer_M2
SBCMNT2: Mounting; spacer_M2
T1, T2, T3, T4, T5, T6, T7, T8, T9, T10, T11, T12, T13, T14, T15, T16: tran_choke_center; TDK_ALT3232M
U1: LattePanda_Mu; LattePanda_Module_H8.0mm_Horizontal
U2, U5, U6: mem_flash_spi; SOIC127PxxxX200-8
U3, U4: RP2350B; QFN40P1000X1000-81
U7, U8: RTL8111H; QFN40P400X400-33
U9: Teensy 4.1; teensy_4.1
U10: H11L1; SOIC254P1030X430-6
U11: CS4272; SOP65P640X970-28
U12: NXES2; murata_nxe2
U13, U14: LDL212DR; SOIC127P600X150-8
U15, U16, U17, U18: OPAMP_DIFF_1; SOP65P490X300-8
U19, U20: AP6335xQ; DFN300X200X90-9
U21: LM5158; QFN50P300X300-17
U22: TPS7A4001; SOP65P490X300-9
U23: ISO7762; SOP635P600X490-16
U24: ISO1640; SOIC127P600X150-8
V1: realee logo; logo_realee_5mm
V2: rohs icon; icon_rohs_
V3: notrash icon; icon_notrash
V4: esd icon; icon_esdwarning_3mm
V5, V6, V7: fiducial; fiducial_1to2_1mm
V8, V9, V10: tooling hole; mechole_2.0mm
V11: serial; serial_8x8
X1, X2: 12MHz, 30ppm+30ppm, 10pF; OSCCC320X250X90
X3, X4: 25MHz, 30ppm+30ppm, 10pF; OSCCC320X250X90
X5: 24.576MHz, 50ppm+20ppm, 18pF; OSCCC320X250X90

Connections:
/Audio/AUDMST.SCL: R165.2, U9.41 (I2C0.SCL), U24.3 (SCL1)
/Audio/AUDMST.SDA: R164.2, U9.40 (I2C0.SDA), U24.2 (SDA1)
/Audio/Audio inputs/IN buffer 1/INBUF.FB+: R82.2, R94.1, R96.1, R110.2, R118.2
/Audio/Audio inputs/IN buffer 1/INBUF.FB-: R83.2, R95.1, R97.1, R111.2, R120.2
/Audio/Audio inputs/IN buffer 1/INBUF.IN+: C142.2, C173.2, D19.3 (M), R94.2, U17.1 (IN-)
/Audio/Audio inputs/IN buffer 1/INBUF.IN-: C143.2, C173.1, D21.3 (M), R95.2, U17.8 (IN+)
/Audio/Audio inputs/IN buffer 1/INBUF.OUT+: C142.1, R96.2, R98.1, U17.4 (OUT+)
/Audio/Audio inputs/IN buffer 1/INBUF.OUT-: C143.1, R97.2, R99.1, U17.5 (OUT-)
/Audio/Audio inputs/IN buffer 2/INBUF.FB+: R88.2, R100.1, R102.1, R112.2, R119.2
/Audio/Audio inputs/IN buffer 2/INBUF.FB-: R89.2, R101.1, R103.1, R113.2, R121.2
/Audio/Audio inputs/IN buffer 2/INBUF.IN+: C149.2, C174.2, D20.3 (M), R100.2, U18.1 (IN-)
/Audio/Audio inputs/IN buffer 2/INBUF.IN-: C150.2, C174.1, D22.3 (M), R101.2, U18.8 (IN+)
/Audio/Audio inputs/IN buffer 2/INBUF.OUT+: C149.1, R102.2, R104.1, U18.4 (OUT+)
/Audio/Audio inputs/IN buffer 2/INBUF.OUT-: C150.1, R103.2, R105.1, U18.5 (OUT-)
/Audio/Audio inputs/LINE1IN.SIG+: C159.2 (-), R110.1, R114.2
/Audio/Audio inputs/LINE1IN.SIG-: C160.2 (-), R111.1, R116.2
/Audio/Audio inputs/LINE2IN.SIG+: C161.2 (-), R112.1, R115.2
/Audio/Audio inputs/LINE2IN.SIG-: C162.2 (-), R113.1, R117.2
/Audio/Audio inputs/MIC1IN.SIG+: C163.2 (-), R82.1, R122.1
/Audio/Audio inputs/MIC1IN.SIG-: C164.2 (-), R83.1, R123.1
/Audio/Audio inputs/MIC2IN.SIG+: C165.2 (-), R88.1, R124.1
/Audio/Audio inputs/MIC2IN.SIG-: C166.2 (-), R89.1, R125.1
/Audio/Audio inputs/MICLINE1.SIG+: C144.1, C153.2, R98.2, U11.17 (AINA+)
/Audio/Audio inputs/MICLINE1.SIG-: C145.2, C153.1, R99.2, U11.16 (AINA-)
/Audio/Audio inputs/MICLINE2.SIG+: C151.1, C154.2, R104.2, U11.18 (AINB+)
/Audio/Audio inputs/MICLINE2.SIG-: C152.2, C154.1, R105.2, U11.19 (AINB-)
/Audio/Audio inputs/VCM: C95.2, C121.2, C130.2, C141.2, C148.2, U11.15 (VCOM), U15.2 (VCOM), U16.2 (VCOM), U17.2 (VCOM), U18.2 (VCOM)
/Audio/Audio inputs/_LINE1IN.SIG+: C159.1 (+), C172.2, J4.T
/Audio/Audio inputs/_LINE1IN.SIG-: C160.1 (+), C170.2, J4.R
/Audio/Audio inputs/_LINE2IN.SIG+: C161.1 (+), C168.2, J5.T
/Audio/Audio inputs/_LINE2IN.SIG-: C162.1 (+), C167.2, J5.R
/Audio/Audio inputs/_MIC1IN.SIG+: C139.1, C163.1 (+), J4.2
/Audio/Audio inputs/_MIC1IN.SIG-: C158.2, C164.1 (+), J4.3
/Audio/Audio inputs/_MIC2IN.SIG+: C146.1, C165.1 (+), J5.2
/Audio/Audio inputs/_MIC2IN.SIG-: C147.2, C166.1 (+), J5.3
/Audio/Audio inputs/~MUTE.L: R106.2, R107.1, U11.23 (~AMUTEC), U15.7 (~PD), U17.7 (~PD)
/Audio/Audio inputs/~MUTE.R: R108.2, R109.1, U11.28 (~BMUTEC), U16.7 (~PD), U18.7 (~PD)
/Audio/Audio outputs/LEFT.SIG+: R76.1, U11.25 (AOUTA+)
/Audio/Audio outputs/LEFT.SIG-: R77.1, U11.24 (AOUTA-)
/Audio/Audio outputs/OUT buffer L/OUT+: C122.1 (+), C126.1, R80.2
/Audio/Audio outputs/OUT buffer L/OUT-: C125.2, C127.1 (+), R81.2
/Audio/Audio outputs/OUT buffer L/OUTBUF.FB+: C118.1, R74.1, R76.2, R78.1
/Audio/Audio outputs/OUT buffer L/OUTBUF.FB-: C117.2, R75.1, R77.2, R79.1
/Audio/Audio outputs/OUT buffer L/OUTBUF.IN+: C123.2, R74.2, U15.1 (IN-)
/Audio/Audio outputs/OUT buffer L/OUTBUF.IN-: C124.2, R75.2, U15.8 (IN+)
/Audio/Audio outputs/OUT buffer L/OUTBUF.OUT+: C123.1, R78.2, R80.1, U15.4 (OUT+)
/Audio/Audio outputs/OUT buffer L/OUTBUF.OUT-: C124.1, R79.2, R81.1, U15.5 (OUT-)
/Audio/Audio outputs/OUT buffer R/OUT+: C135.1, C137.1 (+), R92.2
/Audio/Audio outputs/OUT buffer R/OUT-: C136.2, C138.1 (+), R93.2
/Audio/Audio outputs/OUT buffer R/OUTBUF.FB+: C128.1, R84.2, R86.1, R90.1
/Audio/Audio outputs/OUT buffer R/OUTBUF.FB-: C129.2, R85.2, R87.1, R91.1
/Audio/Audio outputs/OUT buffer R/OUTBUF.IN+: C131.2, R86.2, U16.1 (IN-)
/Audio/Audio outputs/OUT buffer R/OUTBUF.IN-: C132.2, R87.2, U16.8 (IN+)
/Audio/Audio outputs/OUT buffer R/OUTBUF.OUT+: C131.1, R90.2, R92.1, U16.4 (OUT+)
/Audio/Audio outputs/OUT buffer R/OUTBUF.OUT-: C132.1, R91.2, R93.1, U16.5 (OUT-)
/Audio/Audio outputs/OUTL.SIG+: C122.2 (-), J12.SB
/Audio/Audio outputs/OUTL.SIG-: C127.2 (-), J12.RB
/Audio/Audio outputs/OUTR.SIG+: C137.2 (-), J12.ST
/Audio/Audio outputs/OUTR.SIG-: C138.2 (-), J12.RT
/Audio/Audio outputs/RIGHT.SIG+: R84.1, U11.26 (AOUTB+)
/Audio/Audio outputs/RIGHT.SIG-: R85.1, U11.27 (AOUTB-)
/Audio/CODEC/CTL.SCL: R167.2, U11.12 (SDA), U24.6 (SCL2)
/Audio/CODEC/CTL.SDA: R166.2, U11.11 (SCL), U24.7 (SDA2)
/Audio/CODEC/DATA.MCLK: R162.2, U11.3 (MCLK)
/Audio/CODEC/DATA.RXD0: R159.2, U11.6 (SDOUT)
/Audio/CODEC/DATA.TXCLK: R160.2, U11.5 (SCLK)
/Audio/CODEC/DATA.TXD0: R163.2, U11.7 (SDIN)
/Audio/CODEC/DATA.TXFS: R161.2, U11.4 (LRCK)
/Audio/CODEC/~RST: U11.14 (~RST), U23.7 (OUTF)
/Audio/MIDI.RX: JMP1.1, U9.26 (UART8.RX)
/Audio/MIDI.TX: JMP2.1, U9.27 (UART8.TX)
/Audio/Power/REGV48.OUT: C199.2, C208.1 (+), C209.2, R145.1, R147.1, U22.1 (OUT)
/Audio/USB.D+: U1.112 (USB2_P6+), U9.56 (USBH.D+)
/Audio/USB.D-: U1.114 (USB2_P6-), U9.55 (USBH.D-)
/Computer/AUDIO.MIDI.RX: JMP1.3, U1.140 (UART2_RXD)
/Computer/AUDIO.MIDI.TX: JMP2.3, U1.138 (UART2_TXD)
/Computer/BIOS mem/BIOS.IO0: R4.1, U1.159 (SPI_MOSI/SPI_IO0)
/Computer/BIOS mem/BIOS.IO1: R5.1, U1.163 (SPI_MISO/SPI_IO1)
/Computer/BIOS mem/BIOS.IO2: R6.1, U1.161 (SPI_IO2)
/Computer/BIOS mem/BIOS.IO3: R7.1, U1.153 (SPI_IO3)
/Computer/BIOS mem/BIOS.SCK: R2.1, U1.155 (SPI_CLK)
/Computer/BIOS mem/BIOS.SEL: R8.2, R10.1, U1.133 (~BIOS_SEL)
/Computer/BIOS mem/BIOS.~SS: R3.1, R9.2, U1.165 (~SPI_CS)
/Computer/BIOS mem/BIOSMEM.IO0: R4.2, U2.5 (IO0)
/Computer/BIOS mem/BIOSMEM.IO1: R5.2, U2.2 (IO1)
/Computer/BIOS mem/BIOSMEM.IO2: R6.2, U2.3 (IO2)
/Computer/BIOS mem/BIOSMEM.IO3: R7.2, U2.7 (IO3)
/Computer/BIOS mem/BIOSMEM.SCK: R2.2, U2.6 (SCK)
/Computer/BIOS mem/BIOSMEM.~SS: R3.2, U2.1 (~CS)
/Computer/DDIB.CLK+: C83.2, U1.199 (DDIB_TX3+)
/Computer/DDIB.CLK-: C84.2, U1.197 (DDIB_TX3-)
/Computer/DDIB.D0+: C77.2, U1.205 (DDIB_TX2+)
/Computer/DDIB.D0-: C78.2, U1.203 (DDIB_TX2-)
/Computer/DDIB.D1+: C79.2, U1.211 (DDIB_TX1+)
/Computer/DDIB.D1-: C80.2, U1.209 (DDIB_TX1-)
/Computer/DDIB.D2+: C81.2, U1.217 (DDIB_TX0+)
/Computer/DDIB.D2-: C82.2, U1.215 (DDIB_TX0-)
/Computer/DDIB.DDC.CLK: Q2.2 (S), R57.2, U1.171 (DDIB_DDC_SCL)
/Computer/DDIB.DDC.DAT: Q3.2 (S), R59.2, U1.169 (DDIB_DDC_SDA)
/Computer/DDIB.HPD: Q4.2 (S), R61.2, U1.183 (DDIB_HPD)
/Computer/ETHI.HSI0+: C47.2, U1.28 (HSIO2_RX+)
/Computer/ETHI.HSI0-: C48.2, U1.30 (HSIO2_RX-)
/Computer/ETHI.HSO0+: C43.2, U1.25 (HSIO2_TX+)
/Computer/ETHI.HSO0-: C44.2, U1.27 (HSIO2_TX-)
/Computer/ETHI.REFCLK+: U1.85 (REFCLK0+), U8.15 (REFCLK+)
/Computer/ETHI.REFCLK-: U1.87 (REFCLK0-), U8.16 (REFCLK-)
/Computer/ETHI.~WAKE: R18.1, U8.21 (~LANWAKE)
/Computer/ETHX.HSI0+: C45.2, U1.64 (HSIO6_RX+)
/Computer/ETHX.HSI0-: C46.2, U1.66 (HSIO6_RX-)
/Computer/ETHX.HSO0+: C41.2, U1.61 (HSIO6_TX+)
/Computer/ETHX.HSO0-: C42.2, U1.63 (HSIO6_TX-)
/Computer/ETHX.REFCLK+: U1.94 (REFCLK4+), U7.15 (REFCLK+)
/Computer/ETHX.REFCLK-: U1.96 (REFCLK4-), U7.16 (REFCLK-)
/Computer/ETHX.~WAKE: R17.1, U7.21 (~LANWAKE)
/Computer/M2E.HSI0+: J19.35 (PE.HRX0+), U1.34 (HSIO3_RX+)
/Computer/M2E.HSI0-: J19.37 (PE.HRX0-), U1.36 (HSIO3_RX-)
/Computer/M2E.HSO0+: J19.41 (PE.HTX0+), U1.31 (HSIO3_TX+)
/Computer/M2E.HSO0-: J19.43 (PE.HTX0-), U1.33 (HSIO3_TX-)
/Computer/M2E.REFCLK+: J19.47 (PE.REFCLK0+), U1.88 (REFCLK3+)
/Computer/M2E.REFCLK-: J19.49 (PE.REFCLK0-), U1.90 (REFCLK3-)
/Computer/M2M.HSI0+: J13.43 (PE.HRX0+), U1.40 (HSIO8_RX+)
/Computer/M2M.HSI0-: J13.41 (PE.HRX0-), U1.42 (HSIO8_RX-)
/Computer/M2M.HSI1+: J13.31 (PE.HRX1+), U1.46 (HSIO9_RX+)
/Computer/M2M.HSI1-: J13.29 (PE.HRX1-), U1.48 (HSIO9_RX-)
/Computer/M2M.HSI2+: J13.19 (PE.HRX2+), U1.52 (HSIO10_RX+)
/Computer/M2M.HSI2-: J13.17 (PE.HRX2-), U1.54 (HSIO10_RX-)
/Computer/M2M.HSI3+: J13.7 (PE.HRX3+), U1.58 (HSIO11_RX+)
/Computer/M2M.HSI3-: J13.5 (PE.HRX3-), U1.60 (HSIO11_RX-)
/Computer/M2M.HSO0+: J13.49 (PE.HTX0+), U1.37 (HSIO8_TX+)
/Computer/M2M.HSO0-: J13.47 (PE.HTX0-), U1.39 (HSIO8_TX-)
/Computer/M2M.HSO1+: J13.37 (PE.HTX1+), U1.43 (HSIO9_TX+)
/Computer/M2M.HSO1-: J13.35 (PE.HTX1-), U1.45 (HSIO9_TX-)
/Computer/M2M.HSO2+: J13.25 (PE.HTX2+), U1.49 (HSIO10_TX+)
/Computer/M2M.HSO2-: J13.23 (PE.HTX2-), U1.51 (HSIO10_TX-)
/Computer/M2M.HSO3+: J13.13 (PE.HTX3+), U1.55 (HSIO11_TX+)
/Computer/M2M.HSO3-: J13.11 (PE.HTX3-), U1.57 (HSIO11_TX-)
/Computer/M2M.REFCLK+: J13.55 (PE.REFCLK+), U1.97 (REFCLK2+)
/Computer/M2M.REFCLK-: J13.53 (PE.REFCLK-), U1.99 (REFCLK2-)
/Computer/USB2P3.D+: D10.4, J2.7 (BOT_D+), U1.81 (USB2_P3+)
/Computer/USB2P3.D-: D10.5, J2.6 (BOT_D-), U1.79 (USB2_P3-)
/Computer/USB2P4.D+: R11.2, U1.70 (USB2_P4+)
/Computer/USB2P4.D-: R11.1, U1.72 (USB2_P4-)
/Computer/USB2P5.D+: D10.1, J2.3 (TOP_D+), U1.111 (USB2_P5+)
/Computer/USB2P5.D-: D10.2, J2.2 (TOP_D-), U1.109 (USB2_P5-)
/Computer/USB2P7.D+: J19.3 (USB.D+), U1.76 (USB2_P7+)
/Computer/USB2P7.D-: J19.5 (USB.D-), U1.78 (USB2_P7-)
/Computer/USB2P8.D+: R12.2, U1.82 (USB2_P8+)
/Computer/USB2P8.D-: R12.1, U1.84 (USB2_P8-)
/Computer/USB3P2.D+: D13.2, J3.3 (BOT_D+), U1.75 (USB2_P2+)
/Computer/USB3P2.D-: D13.1, J3.2 (BOT_D-), U1.73 (USB2_P2-)
/Computer/USB3P2.SSRX+: D11.4, J3.6 (BOT_SSRX+), U1.16 (HSIO0_RX+)
/Computer/USB3P2.SSRX-: D11.5, J3.5 (BOT_SSRX-), U1.18 (HSIO0_RX-)
/Computer/USB3P2.SSTX+: C34.2, U1.13 (HSIO0_TX+)
/Computer/USB3P2.SSTX-: C33.2, U1.15 (HSIO0_TX-)
/Computer/USBP1.D+: D13.4, J3.12 (TOP_D+), U1.69 (USB2_P1+)
/Computer/USBP1.D-: D13.5, J3.11 (TOP_D-), U1.67 (USB2_P1-)
/Computer/USBP1.SSRX+: D12.4, J3.15 (TOP_SSRX+), U1.22 (HSIO1_RX+)
/Computer/USBP1.SSRX-: D12.5, J3.14 (TOP_SSRX-), U1.24 (HSIO1_RX-)
/Computer/USBP1.SSTX+: C36.2, U1.19 (HSIO1_TX+)
/Computer/USBP1.SSTX-: C35.2, U1.21 (HSIO1_TX-)
/Display/_HDMI.CLK+: C83.1, D15.2, J1.10 (TMDS.CLK+), R56.7
/Display/_HDMI.CLK-: C84.1, D15.1, J1.12 (TMDS.CLK-), R56.8
/Display/_HDMI.D0+: C77.1, D15.5, J1.7 (TMDS.D0+), R56.5
/Display/_HDMI.D0-: C78.1, D15.4, J1.9 (TMDS.D0-), R56.6
/Display/_HDMI.D1+: C79.1, D14.2, J1.4 (TMDS.D1+), R55.7
/Display/_HDMI.D1-: C80.1, D14.1, J1.6 (TMDS.D1-), R55.8
/Display/_HDMI.D2+: C81.1, D14.5, J1.1 (TMDS.D2+), R55.5
/Display/_HDMI.D2-: C82.1, D14.4, J1.3 (TMDS.D2-), R55.6
/External Ethernet/ETH.VCORE: C53.2, C55.2, C57.2, C59.2, C61.2, C63.2, C65.2, U7.3 (AVDD10), U7.8 (AVDD10), U7.22 (DVDD10), U7.24 (REGOUT), U7.30 (AVDD10)
/External Ethernet/ETH.VIO: C67.2, C69.2, C71.2, R17.2, R19.2, R28.1, R30.1, R42.2, U7.11 (AVDD33), U7.23 (VDDREG), U7.32 (AVDD33)
/External Ethernet/ETHPCIE.RX+: C41.1, U7.13 (HSI(PCIE.RX)+)
/External Ethernet/ETHPCIE.RX-: C42.1, U7.14 (HSI(PCIE.RX)-)
/External Ethernet/ETHPCIE.TX+: C45.1, U7.17 (HSO(PCIE.TX)+)
/External Ethernet/ETHPCIE.TX-: C46.1, U7.18 (HSO(PCIE.TX)-)
/External Ethernet/MDI0+: T1.1, U7.1 (MDI0+)
/External Ethernet/MDI0-: T1.2, U7.2 (MDI0-)
/External Ethernet/MDI1+: T5.1, U7.4 (MDI1+)
/External Ethernet/MDI1-: T5.2, U7.5 (MDI1-)
/External Ethernet/MDI2+: T9.1, U7.6 (MDI2+)
/External Ethernet/MDI2-: T9.2, U7.7 (MDI2-)
/External Ethernet/MDI3+: T13.1, U7.9 (MDI3+)
/External Ethernet/MDI3-: T13.2, U7.10 (MDI3-)
/External Ethernet/PAIR0+: J9.1 (C1), T3.4
/External Ethernet/PAIR0-: J9.2 (C2), T3.2
/External Ethernet/PAIR1+: J9.3 (C3), T7.4
/External Ethernet/PAIR1-: J9.4 (C4), T7.2
/External Ethernet/PAIR2+: J9.5 (C5), T11.4
/External Ethernet/PAIR2-: J9.6 (C6), T11.2
/External Ethernet/PAIR3+: J9.7 (C7), T15.4
/External Ethernet/PAIR3-: J9.8 (C8), T15.2
/External Ethernet/_MDI0+: T1.5, T3.5
/External Ethernet/_MDI0-: T1.4, T3.1
/External Ethernet/_MDI1+: T5.5, T7.5
/External Ethernet/_MDI1-: T5.4, T7.1
/External Ethernet/_MDI2+: T9.5, T11.5
/External Ethernet/_MDI2-: T9.4, T11.1
/External Ethernet/_MDI3+: T13.5, T15.5
/External Ethernet/_MDI3-: T13.4, T15.1
/Internal Ethernet/ETH.VCORE: C54.2, C56.2, C58.2, C60.2, C62.2, C64.2, C66.2, U8.3 (AVDD10), U8.8 (AVDD10), U8.22 (DVDD10), U8.24 (REGOUT), U8.30 (AVDD10)
/Internal Ethernet/ETH.VIO: C68.2, C70.2, C72.2, R18.2, R20.2, R29.1, R31.1, R43.2, U8.11 (AVDD33), U8.23 (VDDREG), U8.32 (AVDD33)
/Internal Ethernet/ETHPCIE.RX+: C43.1, U8.13 (HSI(PCIE.RX)+)
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

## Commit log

2026-02-08 initial commit added lattepanda kicad lib added top-arch diagram (70% done)
2026-02-19 added audio reference circuits
2026-02-19 started pwr tree diagram added appnote for phantom power supply
2026-02-22 added lattepanda model and footprint some small modif on symbol so it is normalized
2026-02-22 added skeleton schematic and some pcb placement
    [pandore-audio.kicad_sch, pandore-bios.kicad_sch, pandore-bootctl.kicad_sch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]
2026-02-22 ignore caches files of kicad
2026-02-26 added usb, hdmi and combo xlrtrs connectors resized pcb for something realistic (still wip)
    [pandore-audio-inputs.kicad_sch, pandore-audio.kicad_sch, pandore-cpumod.kicad_sch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]
2026-02-28 added RP2350's crystals added 8p8c shielded with led connector (both the same for now)
    [pandore-eth.kicad_sch, pandore-mcu.kicad_sch, pandore.kicad_pcb]
2026-03-02 added all remaining connectors (only missing M.2 now)
    [pandore-audio-inputs.kicad_sch, pandore-audio-outputs.kicad_sch, pandore-audio.kicad_sch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]
2026-03-05 Added lots to sch and pcb: eth passive, audio codec, midi, teensy Corrected and added support for M.2
    [pandore-audio-codec.kicad_sch, pandore-audio-inputs.kicad_sch, pandore-audio-outputs.kicad_sch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]
2026-03-05 added ref doc for cs4272 audio interface based on teensy
2026-03-07 lots of work done all around
    [pandore-audio-codec.kicad_sch, pandore-audio-inbuf.kicad_sch, pandore-audio-inputs.kicad_sch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]
2026-03-08 added power stuff revised M.2 for higher model and added m.2 mounts added power tap terminals
    [pandore-audio-power.kicad_sch, pandore-audio.kicad_sch, pandore-computer.kicad_sch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]
2026-03-09 Lots of routing done power blocks intra-routing mostly done rp2350 routing mostly done some label cleanup
    [pandore-audio-inbuf.kicad_sch, pandore-audio-power.kicad_sch, pandore-display.kicad_sch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]
2026-03-09 added v50 regulator design from wbdesign
2026-03-10 added i2s/i2c isolation for audio section
    [pandore-audio-codec.kicad_sch, pandore-audio-isolation.kicad_sch, pandore-audio-power.kicad_sch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]
2026-03-10 reshowed the hdmi cable in 3d render
    [pandore.kicad_pcb]
2026-03-10 lots of routing (diff, buses, power) done optimised buffer out
    [pandore-audio-isolation.kicad_sch, pandore-audio-power.kicad_sch, pandore-audio.kicad_sch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]
2026-03-10 added encoder, more routing done, pinout doc added
    [pandore-audio-power.kicad_sch, pandore-mgmtmcu.kicad_sch, pandore-rtmcu.kicad_sch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]
2026-03-11 added display flatflex conn
    [pandore-mgmtmcu.kicad_sch, pandore-power.kicad_sch]
2026-03-11 corrected display conn footprint
    [pandore-mgmtmcu.kicad_sch]
2026-03-11 lcd control circuit added fan interface added rgba output pinout for management mcu accessories done
    [pandore-audio-inbuf.kicad_sch, pandore-audio-inputs.kicad_sch, pandore-audio.kicad_sch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]
2026-03-12 added todos following review
    [pandore-audio-inputs.kicad_sch, pandore-audio-isolation.kicad_sch, pandore-audio-power.kicad_sch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]
2026-03-13 most of board control signals added, routed and defined
    [pandore-audio-codec.kicad_sch, pandore-audio-power.kicad_sch, pandore-audio.kicad_sch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]
2026-03-14 added expansion port and more ctl to rp2350s routing much progress
    [pandore-audio-inputs.kicad_sch, pandore-audio-isolation.kicad_sch, pandore-audio-outputs.kicad_sch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]
2026-03-16 more routing/placement done added 5v load switch 1A each added second fan circuit redone all diffpair routing following new stackup calc added all (?) missing connectors to unused pins
    [pandore-audio-codec.kicad_sch, pandore-audio-isolation.kicad_sch, pandore-audio-power.kicad_sch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]
2026-03-17 added monitor amp with volume knob continue routing all around
    [pandore-audio-codec.kicad_sch, pandore-audio-inbuf.kicad_sch, pandore-audio-monitor.kicad_sch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]
2026-03-17 last sprint almost done, most routing done
    [pandore-audio-codec.kicad_sch, pandore-audio-monitor.kicad_sch, pandore-audio-outputs.kicad_sch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]
2026-03-18 all routed, review starting
    [pandore-audio.kicad_sch, pandore-computer.kicad_sch, pandore-usbport.kicad_sch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]
2026-03-19 finished adding mpn,mfg to all parts, finished routing placement
    [pandore-audio-codec.kicad_sch, pandore-audio-inbuf.kicad_sch, pandore-audio-inputs.kicad_sch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]
2026-03-19 DRC passing
    [pandore-audio-power.kicad_sch, pandore-midi.kicad_sch]
2026-03-20 final design pass for A0 done release artifact created and sent to quote
    [pandore-audio-codec.kicad_sch, pandore-audio-inbuf.kicad_sch, pandore-audio-inputs.kicad_sch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]
2026-03-21 updated to kicad 10 file format
    [pandore-audio-codec.kicad_sch, pandore-audio-inbuf.kicad_sch, pandore-audio-inputs.kicad_sch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]
2026-03-23 Add board renders and Teensy 4.1 audio bridge to README
2026-03-23 Add Teensy 4.1 MIDI bridging role to README
2026-03-23 Fix preamp IC: THS4521 + OPA1656, not THAT1512 (verified against PCBWay BOM)
2026-04-08 Update hardware specs from verified PCBWay BOM
    - Fix I2S isolation: ISO7762FDBQR (not H11L1 — H11L1 is MIDI-only)
    - Add ISO1640BDR isolated I2C for codec control path
    - Add NXE2S1212MC isolated 12V DC/DC for audio domain
    - Fix phantom supply: LM5158 flyback + TPS7A4001 40V LDO post-reg
    - Correct Ethernet: 2x Gigabit RTL8111H-CG PCIe controllers, 2x RJ45
    - Correct USB: 8x USB from LattePanda Mu + 2x USB-C for Teensy 4.1
    - Correct display: 24-pin 0.5mm FPC ZIF, Midas MCOT128064B1V-WM OLED (SSD1309, 128x64)
    - Correct M.2: Key-M PCIe x4 (NVMe) + Key-A+E (WiFi/BT)
    - Add power rails: 12V (main), AV5/AV3P3 (isolated analog), VSTBY
    - Add power ICs table: AP63356Q, LDL212DR, ET20162, LM5158, TPS7A4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
2026-04-08 Update specs: RP2350B substitution, LattePanda variants, DNP parts table
    - Status: note PCBWay RP2350A→B (QFN-80) substitution; binary-compatible
    - Compute: LattePanda Mu N100 vs N305 variant guidance (DFR1147 recommended)
    - Monitor output: specify PTR902-2020K-A103 (audio taper, 20mm shaft)
    - M.2 Key-A+E: add Intel AX210 WiFi 6E + BT 5.3 as tested module
    - Display: update connector description, link to assembly section
    - Add Components Requiring Separate Assembly section: full 12-part DNP
    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

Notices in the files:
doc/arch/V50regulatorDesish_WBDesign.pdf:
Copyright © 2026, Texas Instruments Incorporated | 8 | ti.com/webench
